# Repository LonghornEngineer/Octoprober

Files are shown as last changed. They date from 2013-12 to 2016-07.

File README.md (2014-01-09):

Octoprober
==========

Temperature logger designed to read 8 different K-type thermocouples. Can log data onto a SD card or to a host computer. Uses a character display for settings and viewing data.

Board Files are for Cadsoft Eagle V6.0+

Created by:
Parker Dillmann
The Longhorn Engineer

http://longhornengineer.com/

Disclaimer and licensing information can be found below.
http://longhornengineer.com/diy/disclaimer/

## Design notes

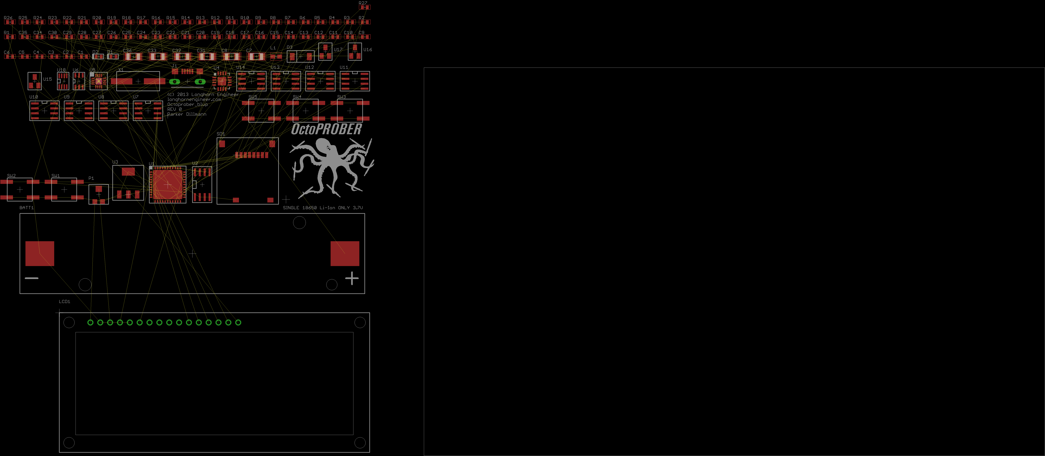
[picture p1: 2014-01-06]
Hardware/Start.png

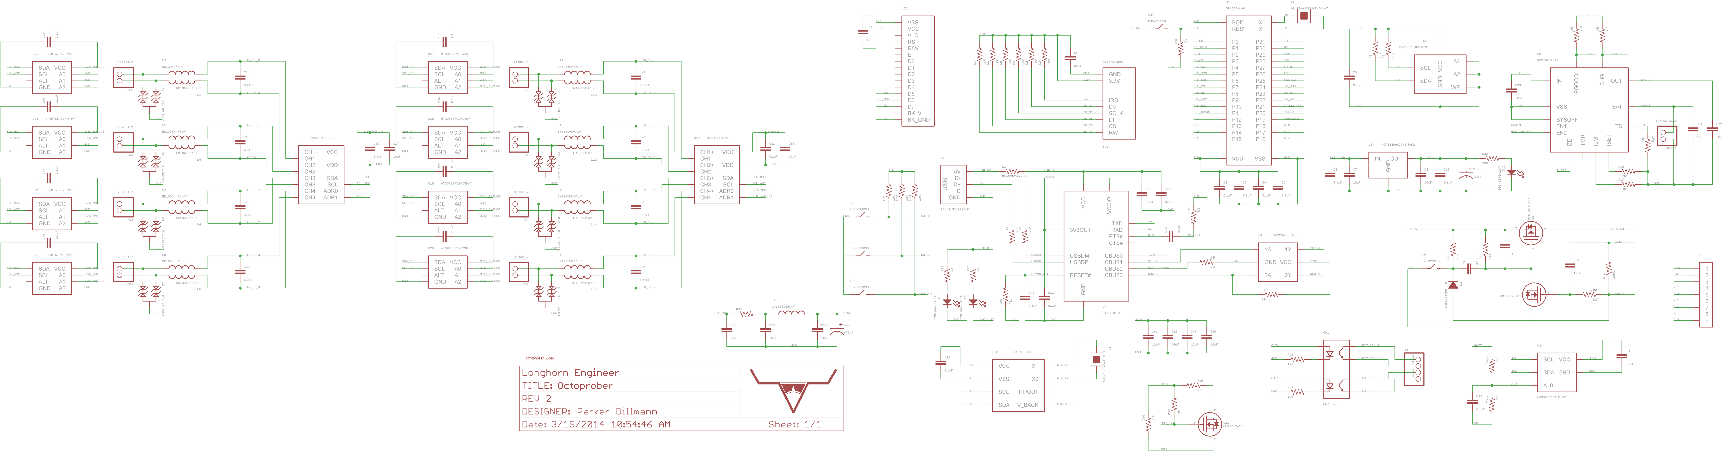
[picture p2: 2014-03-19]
Hardware/Schematic.png

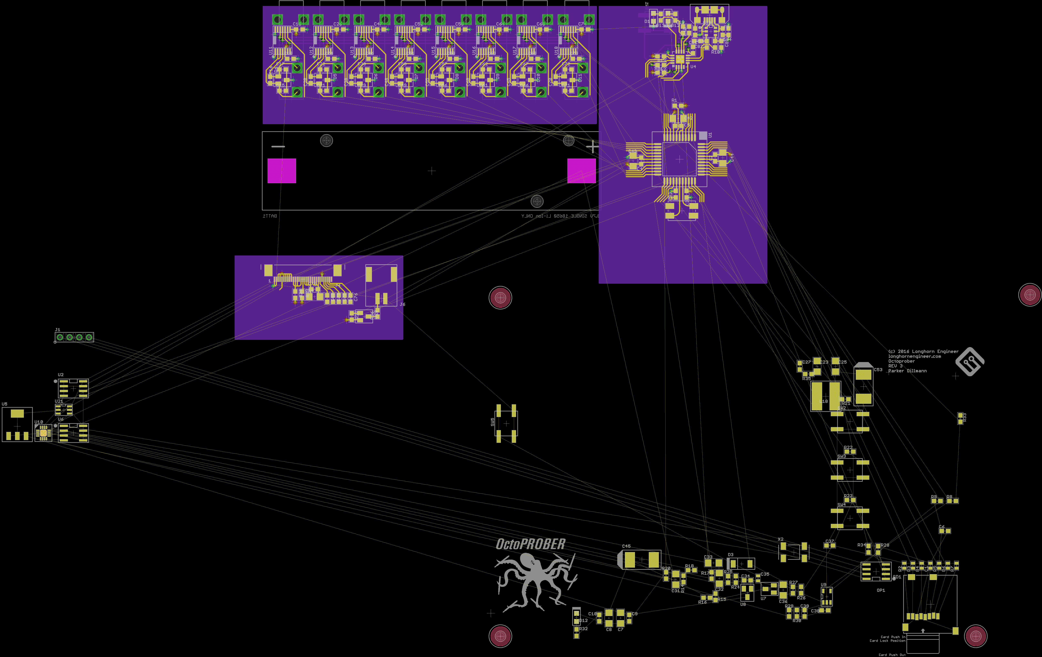
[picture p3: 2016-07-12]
Hardware/Layout.png

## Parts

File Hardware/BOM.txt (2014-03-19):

"Part";"Value";"Device";"Package";"Description";"DNAME";"REVNUM";
"BATT1";"MIKROE-1120";"PH_1X02HEADER_PTH";"HEADER_01X02_PTH";"2 pin connectors";"";"";
"C1";"0.1uF";"CAPACITOR_NON_POLAR0402";"0402";"Capacitor Non Polarized";"";"";
"C2";"0.1uF";"CAPACITOR_NON_POLAR0402";"0402";"Capacitor Non Polarized";"";"";
"C3";"0.1uF";"CAPACITOR_NON_POLAR0402";"0402";"Capacitor Non Polarized";"";"";
"C4";"0.1uF";"CAPACITOR_NON_POLAR0402";"0402";"Capacitor Non Polarized";"";"";
"C5";"0.1uF";"CAPACITOR_NON_POLAR0402";"0402";"Capacitor Non Polarized";"";"";
"C6";"0.1uF";"CAPACITOR_NON_POLAR0402";"0402";"Capacitor Non Polarized";"";"";
"C7";"10uF";"CAPACITOR_NON_POLAR1206";"1206";"Capacitor Non Polarized";"";"";
"C8";"10uF";"CAPACITOR_NON_POLAR1206";"1206";"Capacitor Non Polarized";"";"";
"C9";"0.1uF";"CAPACITOR_NON_POLAR0402";"0402";"Capacitor Non Polarized";"";"";
"C10";"0.1uF";"CAPACITOR_NON_POLAR0402";"0402";"Capacitor Non Polarized";"";"";
"C11";"0.1uF";"CAPACITOR_NON_POLAR0402";"0402";"Capacitor Non Polarized";"";"";
"C12";"0.1uF";"CAPACITOR_NON_POLAR0402";"0402";"Capacitor Non Polarized";"";"";
"C13";"0.1uF";"CAPACITOR_NON_POLAR0402";"0402";"Capacitor Non Polarized";"";"";
"C14";"0.1uF";"CAPACITOR_NON_POLAR0402";"0402";"Capacitor Non Polarized";"";"";
"C15";"0.1uF";"CAPACITOR_NON_POLAR0402";"0402";"Capacitor Non Polarized";"";"";
"C16";"0.01uF";"CAPACITOR_NON_POLAR0402";"0402";"Capacitor Non Polarized";"";"";
"C17";"10uF";"CAPACITOR_NON_POLAR0402";"0402";"Capacitor Non Polarized";"";"";
"C18";"0.01uF";"CAPACITOR_NON_POLAR0402";"0402";"Capacitor Non Polarized";"";"";
"C19";"10uF";"CAPACITOR_NON_POLAR0402";"0402";"Capacitor Non Polarized";"";"";
"C20";"0.01uF";"CAPACITOR_NON_POLAR0402";"0402";"Capacitor Non Polarized";"";"";
"C21";"0.1uF";"CAPACITOR_NON_POLAR0402";"0402";"Capacitor Non Polarized";"";"";
"C22";"0.01uF";"CAPACITOR_NON_POLAR0402";"0402";"Capacitor Non Polarized";"";"";
"C23";"10uF";"CAPACITOR_NON_POLAR0402";"0402";"Capacitor Non Polarized";"";"";
"C24";"0.01uF";"CAPACITOR_NON_POLAR0402";"0402";"Capacitor Non Polarized";"";"";
"C25";"10uF";"CAPACITOR_NON_POLAR0402";"0402";"Capacitor Non Polarized";"";"";
"C26";"0.01uF";"CAPACITOR_NON_POLAR0402";"0402";"Capacitor Non Polarized";"";"";
"C27";"1uF";"CAPACITOR_NON_POLAR0402";"0402";"Capacitor Non Polarized";"";"";
"C28";"0.01uF";"CAPACITOR_NON_POLAR0402";"0402";"Capacitor Non Polarized";"";"";
"C29";"0.1uF";"CAPACITOR_NON_POLAR0402";"0402";"Capacitor Non Polarized";"";"";
"C30";"0.01uF";"CAPACITOR_NON_POLAR0402";"0402";"Capacitor Non Polarized";"";"";
"C31";"10uF";"CAPACITOR_NON_POLAR1206";"1206";"Capacitor Non Polarized";"";"";
"C32";"10uF";"CAPACITOR_NON_POLAR1206";"1206";"Capacitor Non Polarized";"";"";
"C33";"10uF";"CAPACITOR_NON_POLAR1206";"1206";"Capacitor Non Polarized";"";"";
"C34";"0.1uF";"CAPACITOR_NON_POLAR0402";"0402";"Capacitor Non Polarized";"";"";
"C35";"0.1uF";"CAPACITOR_NON_POLAR0402";"0402";"Capacitor Non Polarized";"";"";
"C36";"10uF";"CAPACITOR_NON_POLAR1206";"1206";"Capacitor Non Polarized";"";"";
"C37";"0.1uF";"CAPACITOR_NON_POLAR0402";"0402";"Capacitor Non Polarized";"";"";
"C38";"0.1uF";"CAPACITOR_NON_POLAR0402";"0402";"Capacitor Non Polarized";"";"";
"C39";"0.1uF";"CAPACITOR_NON_POLAR0402";"0402";"Capacitor Non Polarized";"";"";
"C40";"0.1uF";"CAPACITOR_NON_POLAR0402";"0402";"Capacitor Non Polarized";"";"";
"C41";"10uF";"CAPACITOR_NON_POLAR0402";"0402";"Capacitor Non Polarized";"";"";
"C42";"10uF";"CAPACITOR_NON_POLAR0402";"0402";"Capacitor Non Polarized";"";"";
"C43";"10uF";"CAPACITOR_NON_POLAR0402";"0402";"Capacitor Non Polarized";"";"";
"C44";"10uF";"CAPACITOR_NON_POLAR0402";"0402";"Capacitor Non Polarized";"";"";
"C45";"470uF";"CAPACITOR_POLARIZEDCASE_D";"CASE_D";"Polarized capacitors";"";"";
"C46";"0.1uF";"CAPACITOR_NON_POLAR0402";"0402";"Capacitor Non Polarized";"";"";
"C47";"0.1uF";"CAPACITOR_NON_POLAR0402";"0402";"Capacitor Non Polarized";"";"";
"C48";"0.1uF";"CAPACITOR_NON_POLAR0402";"0402";"Capacitor Non Polarized";"";"";
"C49";"0.1uF";"CAPACITOR_NON_POLAR0402";"0402";"Capacitor Non Polarized";"";"";
"C50";"0.1uF";"CAPACITOR_NON_POLAR0402";"0402";"Capacitor Non Polarized";"";"";
"C51";"0.1uF";"CAPACITOR_NON_POLAR0402";"0402";"Capacitor Non Polarized";"";"";
"C52";"0.1uF";"CAPACITOR_NON_POLAR0402";"0402";"Capacitor Non Polarized";"";"";
"C53";"470uF";"CAPACITOR_POLARIZEDCASE_D";"CASE_D";"Polarized capacitors";"";"";
"C54";"1uF";"CAPACITOR_NON_POLAR0402";"0402";"Capacitor Non Polarized";"";"";
"D1";"598-8070-107F";"LED_SINGLE0402";"LED_0402";"";"";"";
"D2";"598-8070-107F";"LED_SINGLE0402";"LED_0402";"";"";"";
"D3";"PMEG6030EP,115";"DIODESOD-128";"SOD-128";"Diode - Single";"";"";
"D4";"NUP2105LT1G";"TVS_DIODE_DUALSOT-23";"SOT-23";"";"";"";
"D5";"NUP2105LT1G";"TVS_DIODE_DUALSOT-23";"SOT-23";"";"";"";
"D6";"NUP2105LT1G";"TVS_DIODE_DUALSOT-23";"SOT-23";"";"";"";
"D7";"NUP2105LT1G";"TVS_DIODE_DUALSOT-23";"SOT-23";"";"";"";
"D8";"NUP2105LT1G";"TVS_DIODE_DUALSOT-23";"SOT-23";"";"";"";
"D9";"NUP2105LT1G";"TVS_DIODE_DUALSOT-23";"SOT-23";"";"";"";
"D10";"NUP2105LT1G";"TVS_DIODE_DUALSOT-23";"SOT-23";"";"";"";
"D11";"NUP2105LT1G";"TVS_DIODE_DUALSOT-23";"SOT-23";"";"";"";
"D12";"598-8070-107F";"LED_SINGLE0402";"LED_0402";"";"";"";
"FU";"";"PH_1X09PTH";"HEADER_01X09_PTH";"";"";"";
"J1";"10118193-0001LF";"USB10118193-0001LF";"10118193-0001LF";"";"";"";
"J2";"";"PH_1X04HEADER_PTH";"HEADER_01X04_PTH";"4 Pin Connectors";"";"";
"L1";"MI0603K300R-10";"RESISTOR0603";"0603";"Resistors";"";"";
"L2";"BK1005HM471-T";"INDUCTOR0402";"0402";"Inductors";"";"";
"L3";"BK1005HM471-T";"INDUCTOR0402";"0402";"Inductors";"";"";
"L4";"BK1005HM471-T";"INDUCTOR0402";"0402";"Inductors";"";"";
"L5";"BK1005HM471-T";"INDUCTOR0402";"0402";"Inductors";"";"";
"L6";"BK1005HM471-T";"INDUCTOR0402";"0402";"Inductors";"";"";
"L7";"BK1005HM471-T";"INDUCTOR0402";"0402";"Inductors";"";"";
"L8";"BK1005HM471-T";"INDUCTOR0402";"0402";"Inductors";"";"";
"L9";"BK1005HM471-T";"INDUCTOR0402";"0402";"Inductors";"";"";
"L10";"BK1005HM471-T";"INDUCTOR0402";"0402";"Inductors";"";"";
"L11";"BK1005HM471-T";"INDUCTOR0402";"0402";"Inductors";"";"";
"L12";"BK1005HM471-T";"INDUCTOR0402";"0402";"Inductors";"";"";
"L13";"BK1005HM471-T";"INDUCTOR0402";"0402";"Inductors";"";"";
"L14";"BK1005HM471-T";"INDUCTOR0402";"0402";"Inductors";"";"";
"L15";"BK1005HM471-T";"INDUCTOR0402";"0402";"Inductors";"";"";
"L16";"BK1005HM471-T";"INDUCTOR0402";"0402";"Inductors";"";"";
"L17";"BK1005HM471-T";"INDUCTOR0402";"0402";"Inductors";"";"";
"L18";"LK1608100K-T";"INDUCTOR0603";"0603";"Inductors";"";"";
"LCD1";"";"HD44780_LCD1602_COUNTERSINK";"CHAR_DISPLAY_1602_COUNTERSINK";"";"";"";
"OP1";"ACPL-227";"ACPL-227SOIC-8";"SOIC-8";"";"";"";
"R1";"10K";"RESISTOR0402";"0402";"Resistors";"";"";
"R2";"10K";"RESISTOR0402";"0402";"Resistors";"";"";
"R3";"10K";"RESISTOR0402";"0402";"Resistors";"";"";
"R4";"10K";"RESISTOR0402";"0402";"Resistors";"";"";
"R5";"10K";"RESISTOR0402";"0402";"Resistors";"";"";
"R6";"10K";"RESISTOR0402";"0402";"Resistors";"";"";
"R7";"10K";"RESISTOR0402";"0402";"Resistors";"";"";
"R8";"10K";"RESISTOR0402";"0402";"Resistors";"";"";
"R9";"10K";"RESISTOR0402";"0402";"Resistors";"";"";
"R10";"22";"RESISTOR0402";"0402";"Resistors";"";"";
"R11";"22";"RESISTOR0402";"0402";"Resistors";"";"";
"R12";"330";"RESISTOR0402";"0402";"Resistors";"";"";
"R13";"330";"RESISTOR0402";"0402";"Resistors";"";"";
"R14";"10K";"RESISTOR0402";"0402";"Resistors";"";"";
"R15";"10K";"RESISTOR0402";"0402";"Resistors";"";"";
"R16";"10K";"RESISTOR0402";"0402";"Resistors";"";"";
"R17";"1.18K";"RESISTOR0402";"0402";"Resistors";"";"";
"R18";"1.13K";"RESISTOR0402";"0402";"Resistors";"";"";
"R19";"10K";"RESISTOR0402";"0402";"Resistors";"";"";
"R20";"10K";"RESISTOR0402";"0402";"Resistors";"";"";
"R21";"10K";"RESISTOR0402";"0402";"Resistors";"";"";
"R22";"10K";"RESISTOR0402";"0402";"Resistors";"";"";
"R23";"10K";"RESISTOR0402";"0402";"Resistors";"";"";
"R24";"100K";"RESISTOR0402";"0402";"Resistors";"";"";
"R25";"10K";"RESISTOR0402";"0402";"Resistors";"";"";
"R26";"100K";"RESISTOR0402";"0402";"Resistors";"";"";
"R27";"300K";"RESISTOR0402";"0402";"Resistors";"";"";
"R28";"120";"RESISTOR0402";"0402";"Resistors";"";"";
"R29";"100K";"RESISTOR0402";"0402";"Resistors";"";"";
"R30";"254K";"RESISTOR0402";"0402";"Resistors";"";"";
"R31";"10K";"RESISTOR0402";"0402";"Resistors";"";"";
"R32";"330";"RESISTOR0402";"0402";"Resistors";"";"";
"R33";"10K";"RESISTOR0402";"0402";"Resistors";"";"";
"R34";"120";"RESISTOR0402";"0402";"Resistors";"";"";
"R35";"1";"RESISTOR0402";"0402";"Resistors";"";"";
"R36";"10K";"RESISTOR0402";"0402";"Resistors";"";"";
"R37";"560";"RESISTOR0402";"0402";"Resistors";"";"";
"R38";"560";"RESISTOR0402";"0402";"Resistors";"";"";
"SD1";"502570-0893";"SD_CARD502570-0893";"502570-0893";"";"";"";
"SW1";"EVQ-Q2203W";"SPSTEVQ-Q2203W";"EVQ-Q2203W";"SPST Switches";"";"";
"SW2";"EVQ-Q2203W";"SPSTEVQ-Q2203W";"EVQ-Q2203W";"SPST Switches";"";"";
"SW3";"EVQ-Q2203W";"SPSTEVQ-Q2203W";"EVQ-Q2203W";"SPST Switches";"";"";
"SW4";"EVQ-Q2203W";"SPSTEVQ-Q2203W";"EVQ-Q2203W";"SPST Switches";"";"";
"SW5";"EVQ-Q2203W";"SPSTEVQ-Q2203W";"EVQ-Q2203W";"SPST Switches";"";"";
"TC1";"282834-2";"PH_1X02SCREW_TERM";"HEADER_01X02_PTH_SCREWTERM";"2 pin connectors";"";"";
"TC2";"282834-2";"PH_1X02SCREW_TERM";"HEADER_01X02_PTH_SCREWTERM";"2 pin connectors";"";"";
"TC3";"282834-2";"PH_1X02SCREW_TERM";"HEADER_01X02_PTH_SCREWTERM";"2 pin connectors";"";"";
"TC4";"282834-2";"PH_1X02SCREW_TERM";"HEADER_01X02_PTH_SCREWTERM";"2 pin connectors";"";"";
"TC5";"282834-2";"PH_1X02SCREW_TERM";"HEADER_01X02_PTH_SCREWTERM";"2 pin connectors";"";"";
"TC6";"282834-2";"PH_1X02SCREW_TERM";"HEADER_01X02_PTH_SCREWTERM";"2 pin connectors";"";"";
"TC7";"282834-2";"PH_1X02SCREW_TERM";"HEADER_01X02_PTH_SCREWTERM";"2 pin connectors";"";"";
"TC8";"282834-2";"PH_1X02SCREW_TERM";"HEADER_01X02_PTH_SCREWTERM";"2 pin connectors";"";"";
"U$1";"LHE_FRAME";"LHE_FRAME";"LHE_FRAME";"";"Parker Dillmann";"REV 2";
"U$2";"OCTOPROBER_LOGONORMAL";"OCTOPROBER_LOGONORMAL";"OCTOPROBER_LOGO";"";"";"";
"U1";"P8X32A-M44";"P8X32A_PROPELLERQFN-44";"QFN-44";"";"";"";
"U2";"CAT24C512WI-GT3";"CAT24M01XI-T2SOIC-8_W";"SOIC-8_W";"";"";"";
"U3";"ADP3338AKCZ-3.3-RL";"FIXED_VOLTAGE_REGSOT-223_ALT";"SOT-223";"";"";"";
"U4";"FT230XQ-R";"FT230XQFN-16";"QFN-16";"Manufacturer Part #: FT230XS-R";"";"";
"U5";"BQ24075RGTT";"BQ2407XQFN-16";"QFN-16_BOT_PAD";"";"";"";
"U6";"74HC2G04GV,125";"74HCT2G04GV,125TTSOP-6";"TTSOP-6";"";"";"";
"U7";"PMV22EN,215";"MOSFET_N-CHANNEL_SINGLESOT-23";"SOT-23";"Mosfet - N-Channel - Single";"";"";
"U8";"PMV160UP,215";"MOSFET_P-CHANNEL_SINGLESOT-23";"SOT-23";"";"";"";
"U9";"MCP3021A5T-E/OT";"MCP3021SOT-23A";"SOT-23A";"";"";"";
"U10";"DS1340Z-33+";"DS1340SOIC-8";"SOIC-8";"";"";"";
"U11";"MCP3424-E/ST";"MCP3424TTSOP-14";"TTSOP-14";"";"";"";
"U12";"MCP3424-E/ST";"MCP3424TTSOP-14";"TTSOP-14";"";"";"";
"U13";"AT30TSE752-XM8-T";"AT30TSEXXXMSOP-8";"MSOP-8";"";"";"";
"U14";"AT30TSE752-XM8-T";"AT30TSEXXXMSOP-8";"MSOP-8";"";"";"";
"U15";"AT30TSE752-XM8-T";"AT30TSEXXXMSOP-8";"MSOP-8";"";"";"";
"U16";"AT30TSE752-XM8-T";"AT30TSEXXXMSOP-8";"MSOP-8";"";"";"";
"U17";"AT30TSE752-XM8-T";"AT30TSEXXXMSOP-8";"MSOP-8";"";"";"";
"U18";"AT30TSE752-XM8-T";"AT30TSEXXXMSOP-8";"MSOP-8";"";"";"";
"U19";"AT30TSE752-XM8-T";"AT30TSEXXXMSOP-8";"MSOP-8";"";"";"";
"U20";"AT30TSE752-XM8-T";"AT30TSEXXXMSOP-8";"MSOP-8";"";"";"";
"U21";"PMV22EN,215";"MOSFET_N-CHANNEL_SINGLESOT-23";"SOT-23";"Mosfet - N-Channel - Single";"";"";
"X1";"ABLS3-6.000MHZ-D4Y-T";"CRYSTALHC-49";"HC-49/US_SM";"";"";"";
"X2";"ABS25-32.768KHz-1-T";"CRYSTAL8MM_X_3.8MM";"8MM_X_3.8MM";"";"";"";

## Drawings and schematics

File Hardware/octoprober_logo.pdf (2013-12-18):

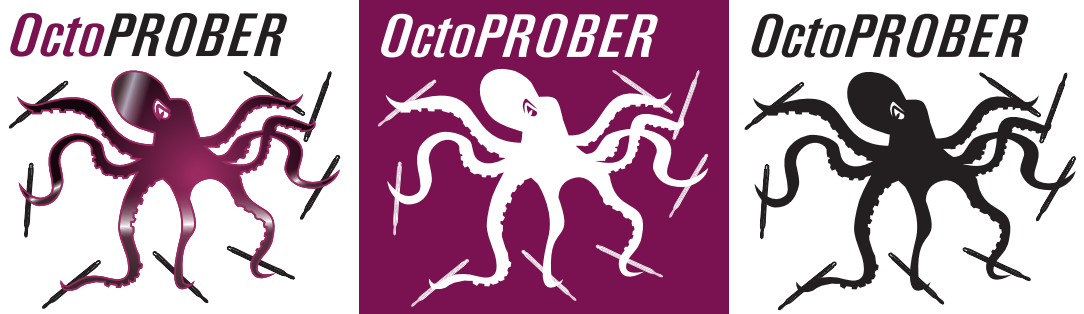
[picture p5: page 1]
OctoPROBER

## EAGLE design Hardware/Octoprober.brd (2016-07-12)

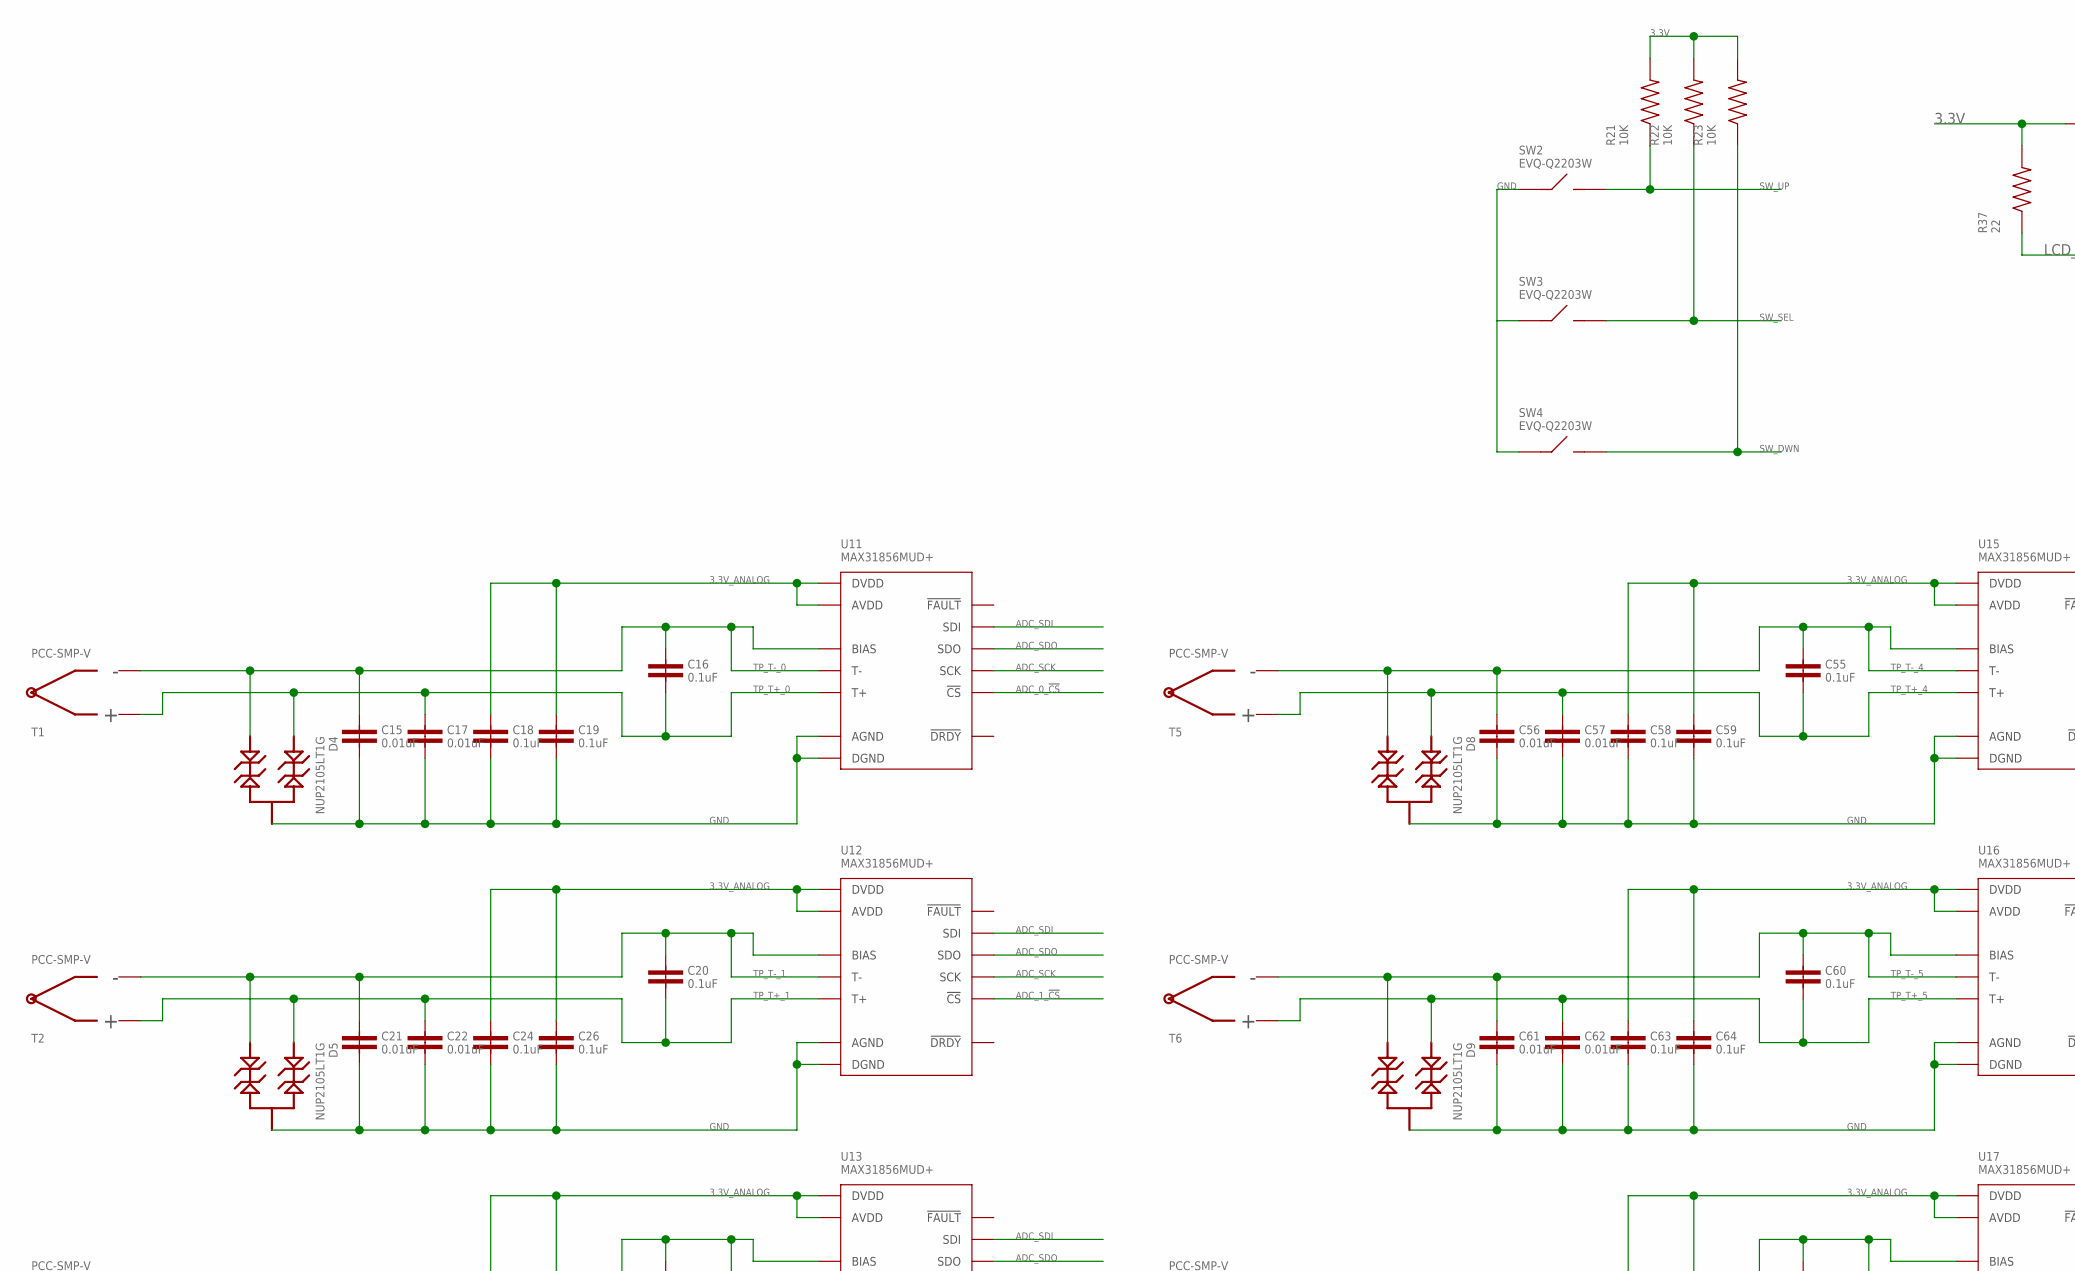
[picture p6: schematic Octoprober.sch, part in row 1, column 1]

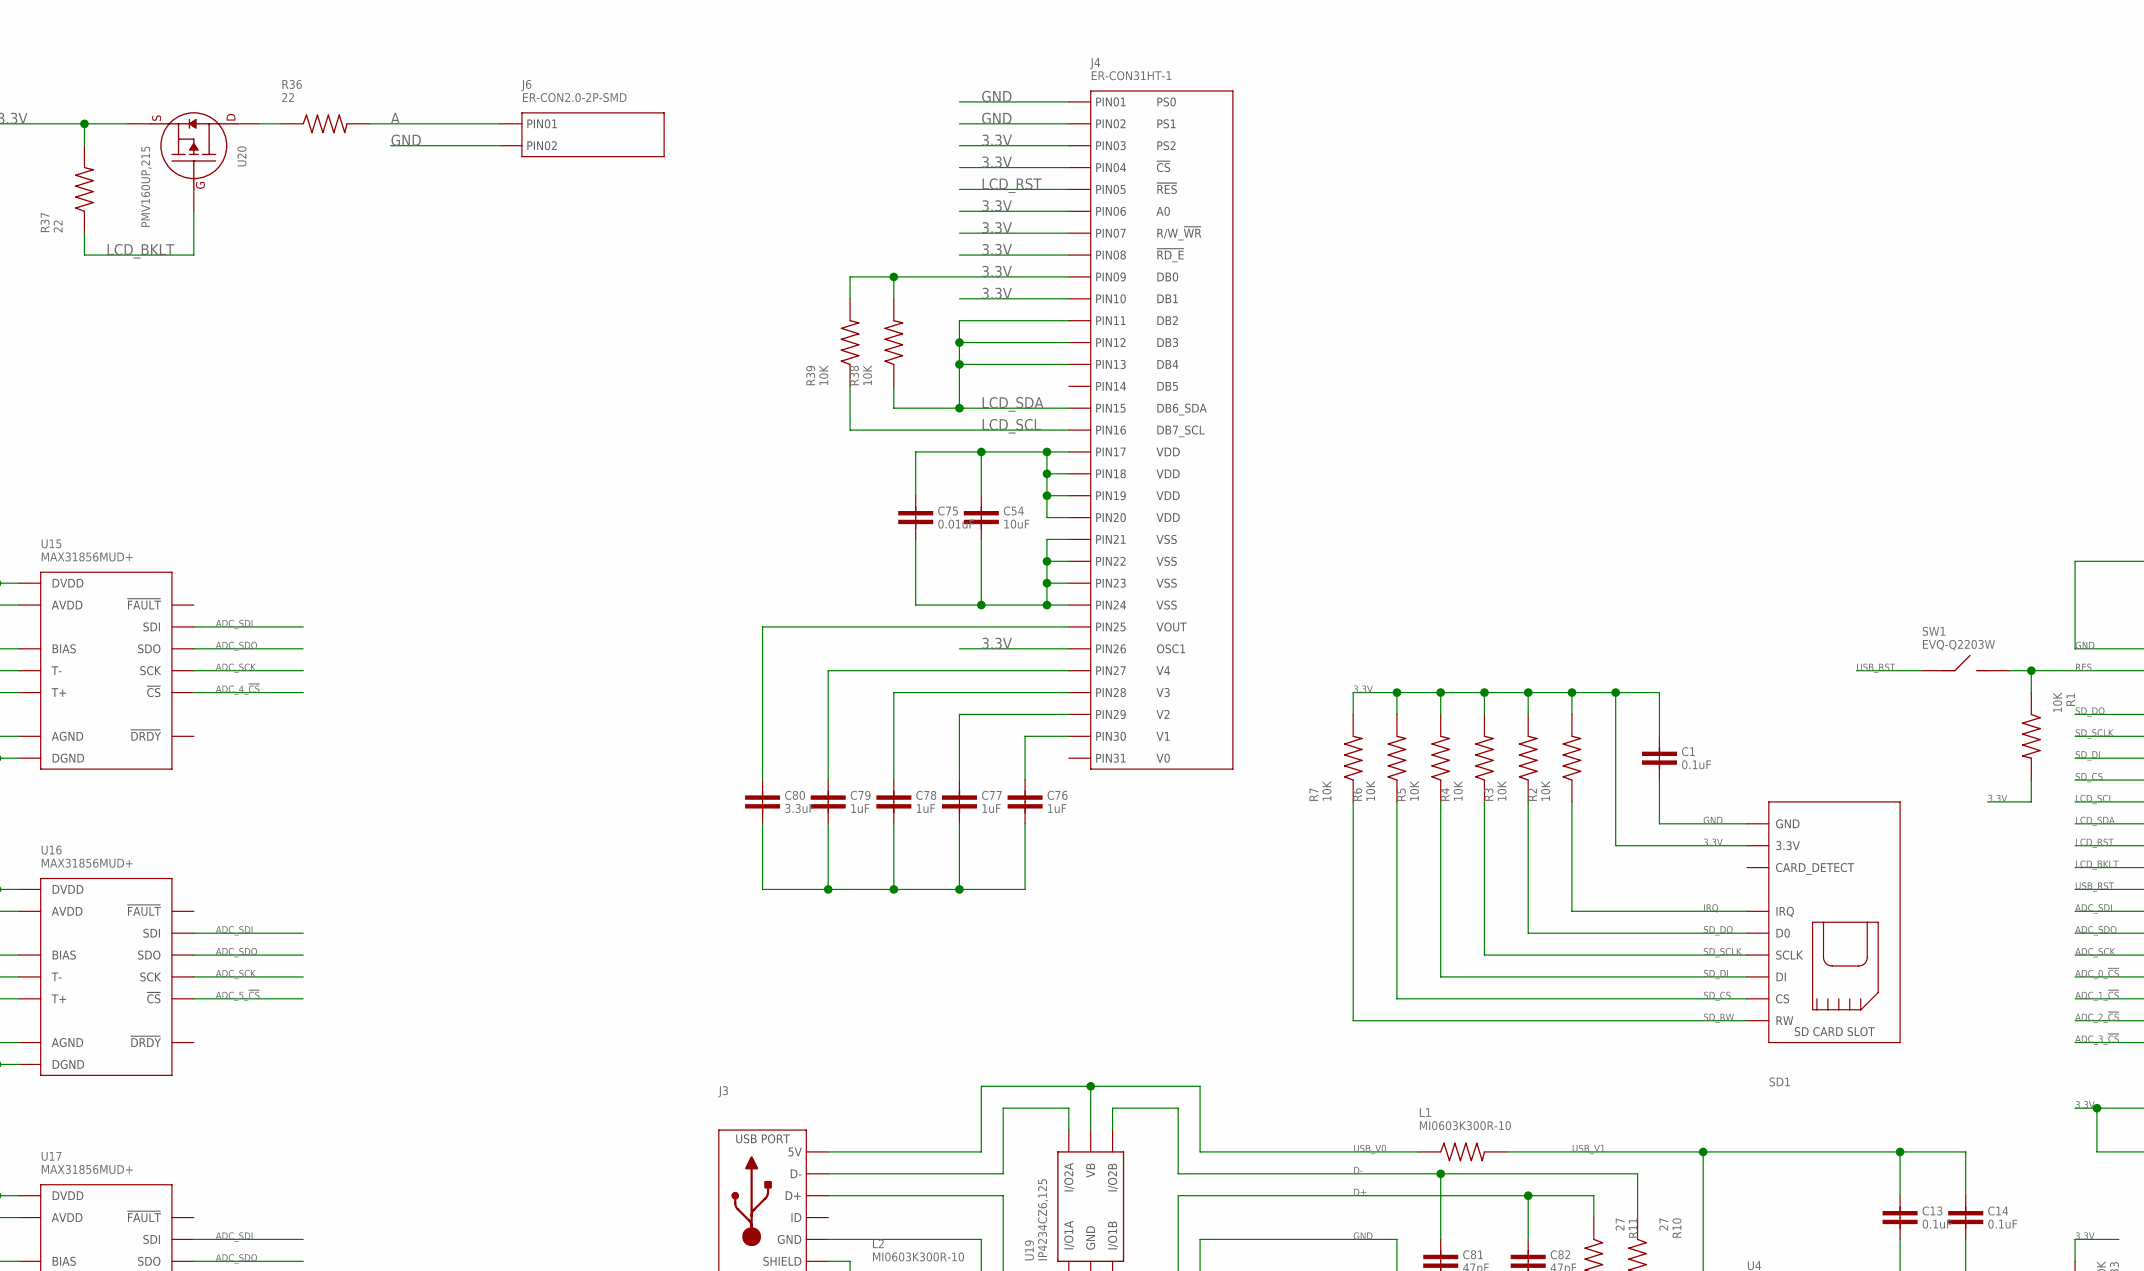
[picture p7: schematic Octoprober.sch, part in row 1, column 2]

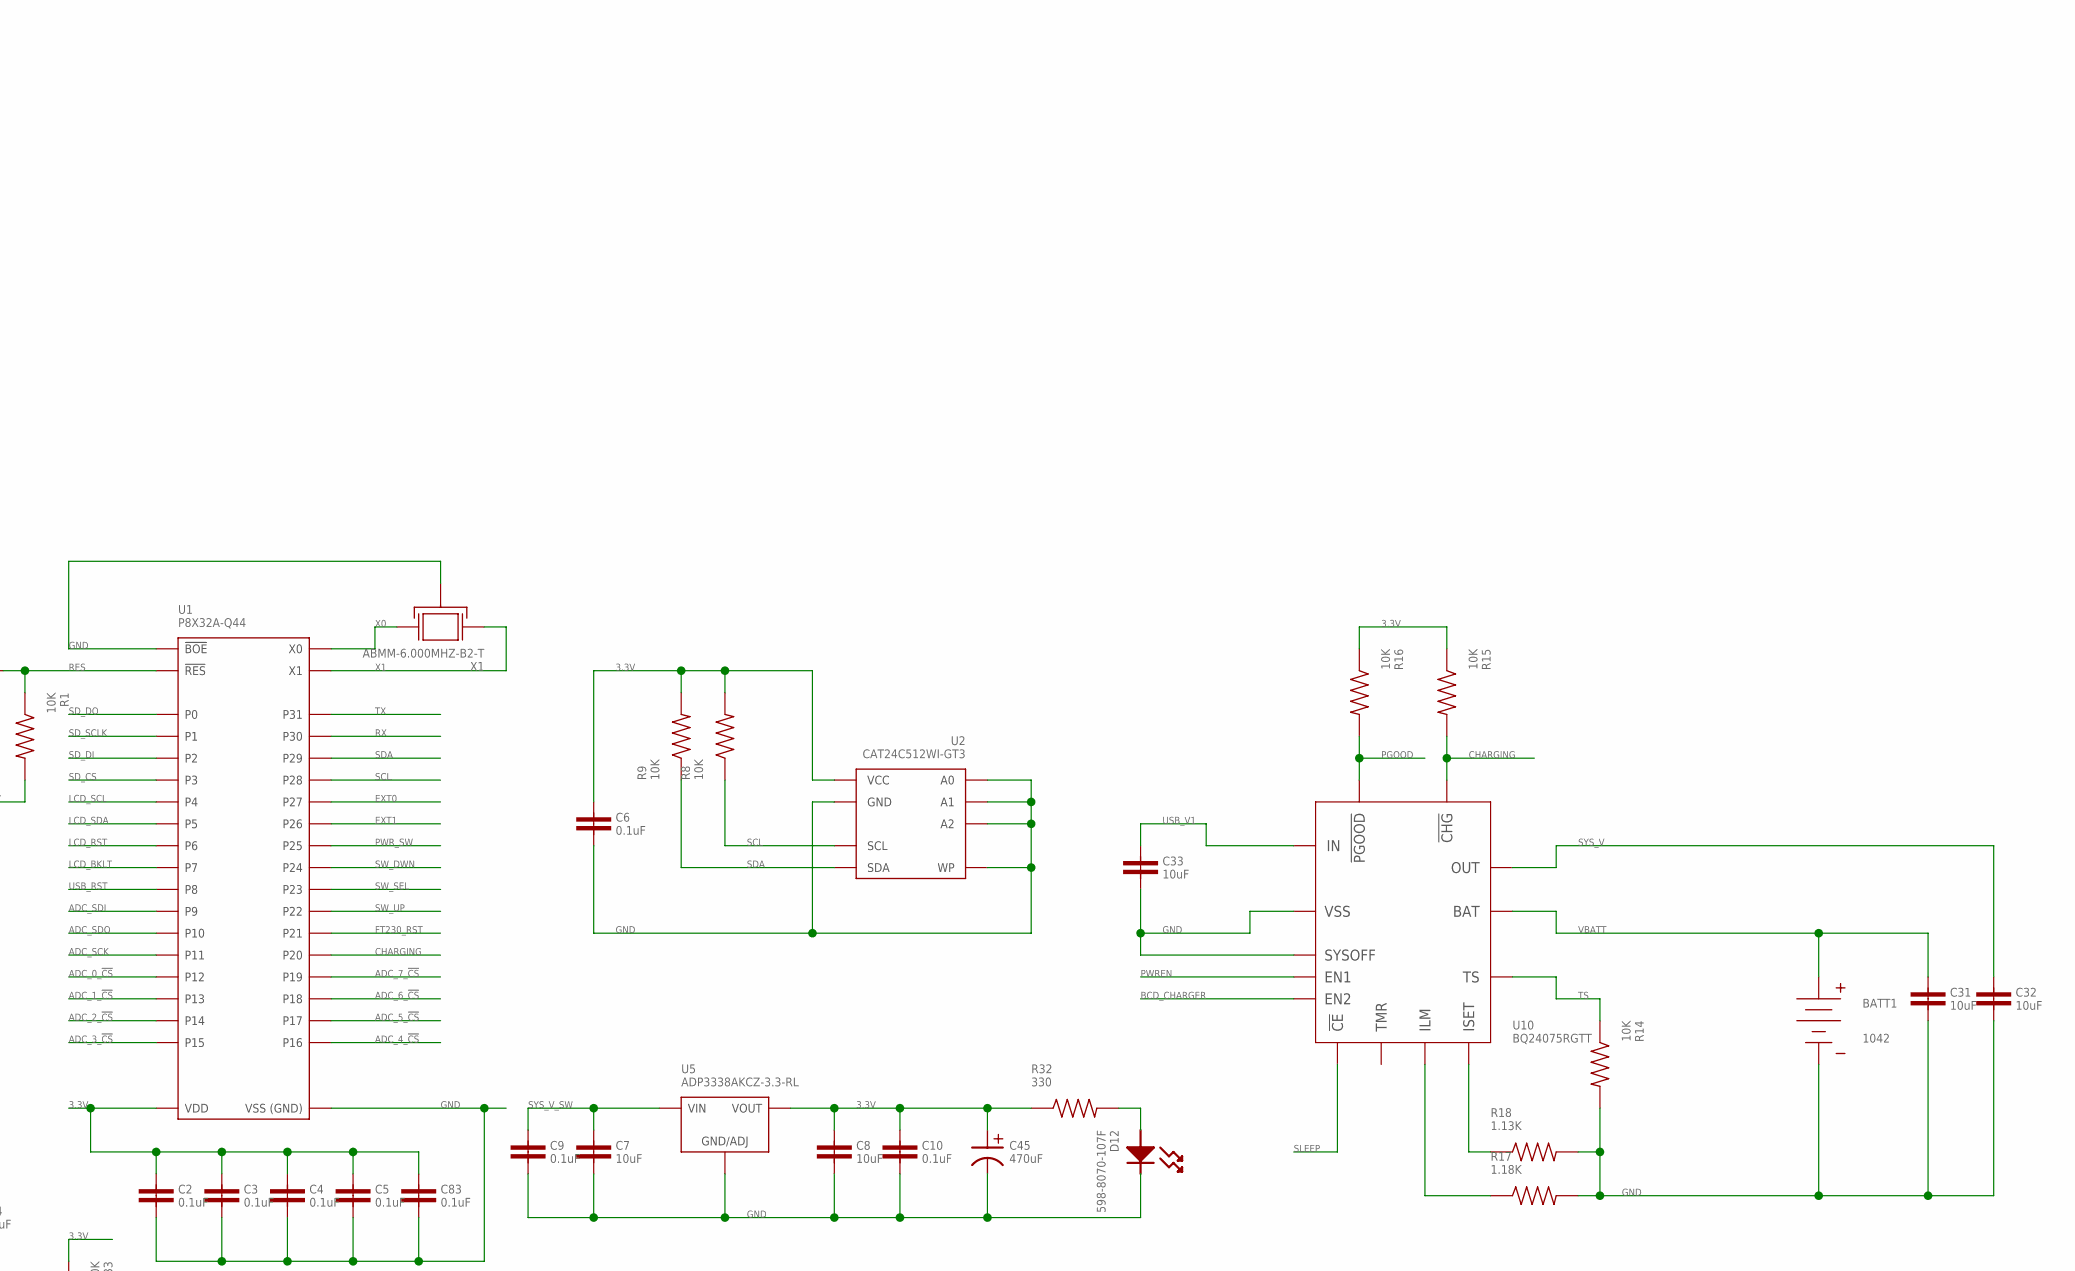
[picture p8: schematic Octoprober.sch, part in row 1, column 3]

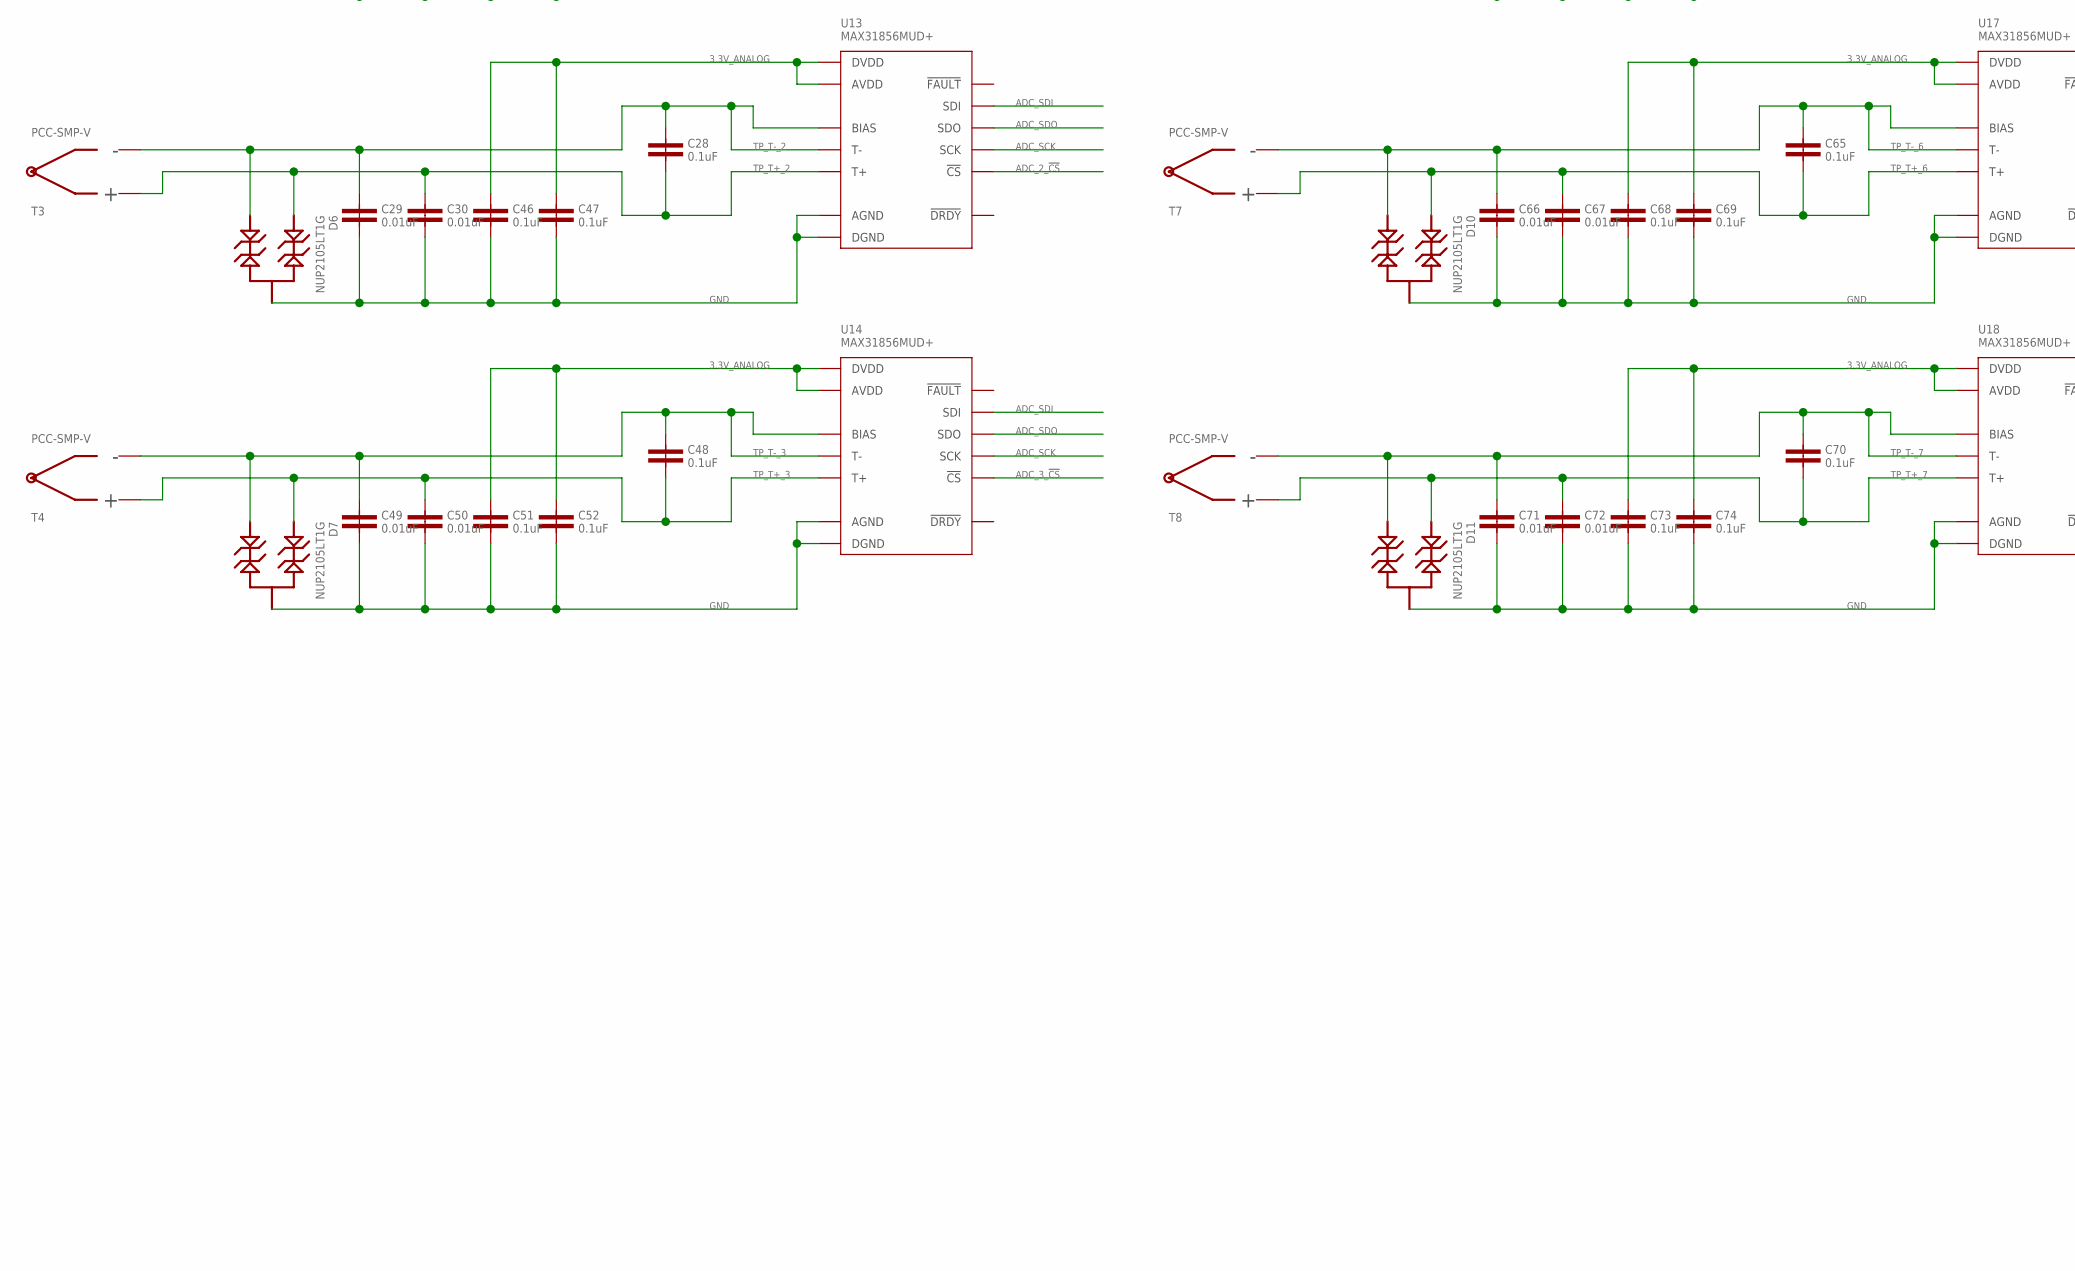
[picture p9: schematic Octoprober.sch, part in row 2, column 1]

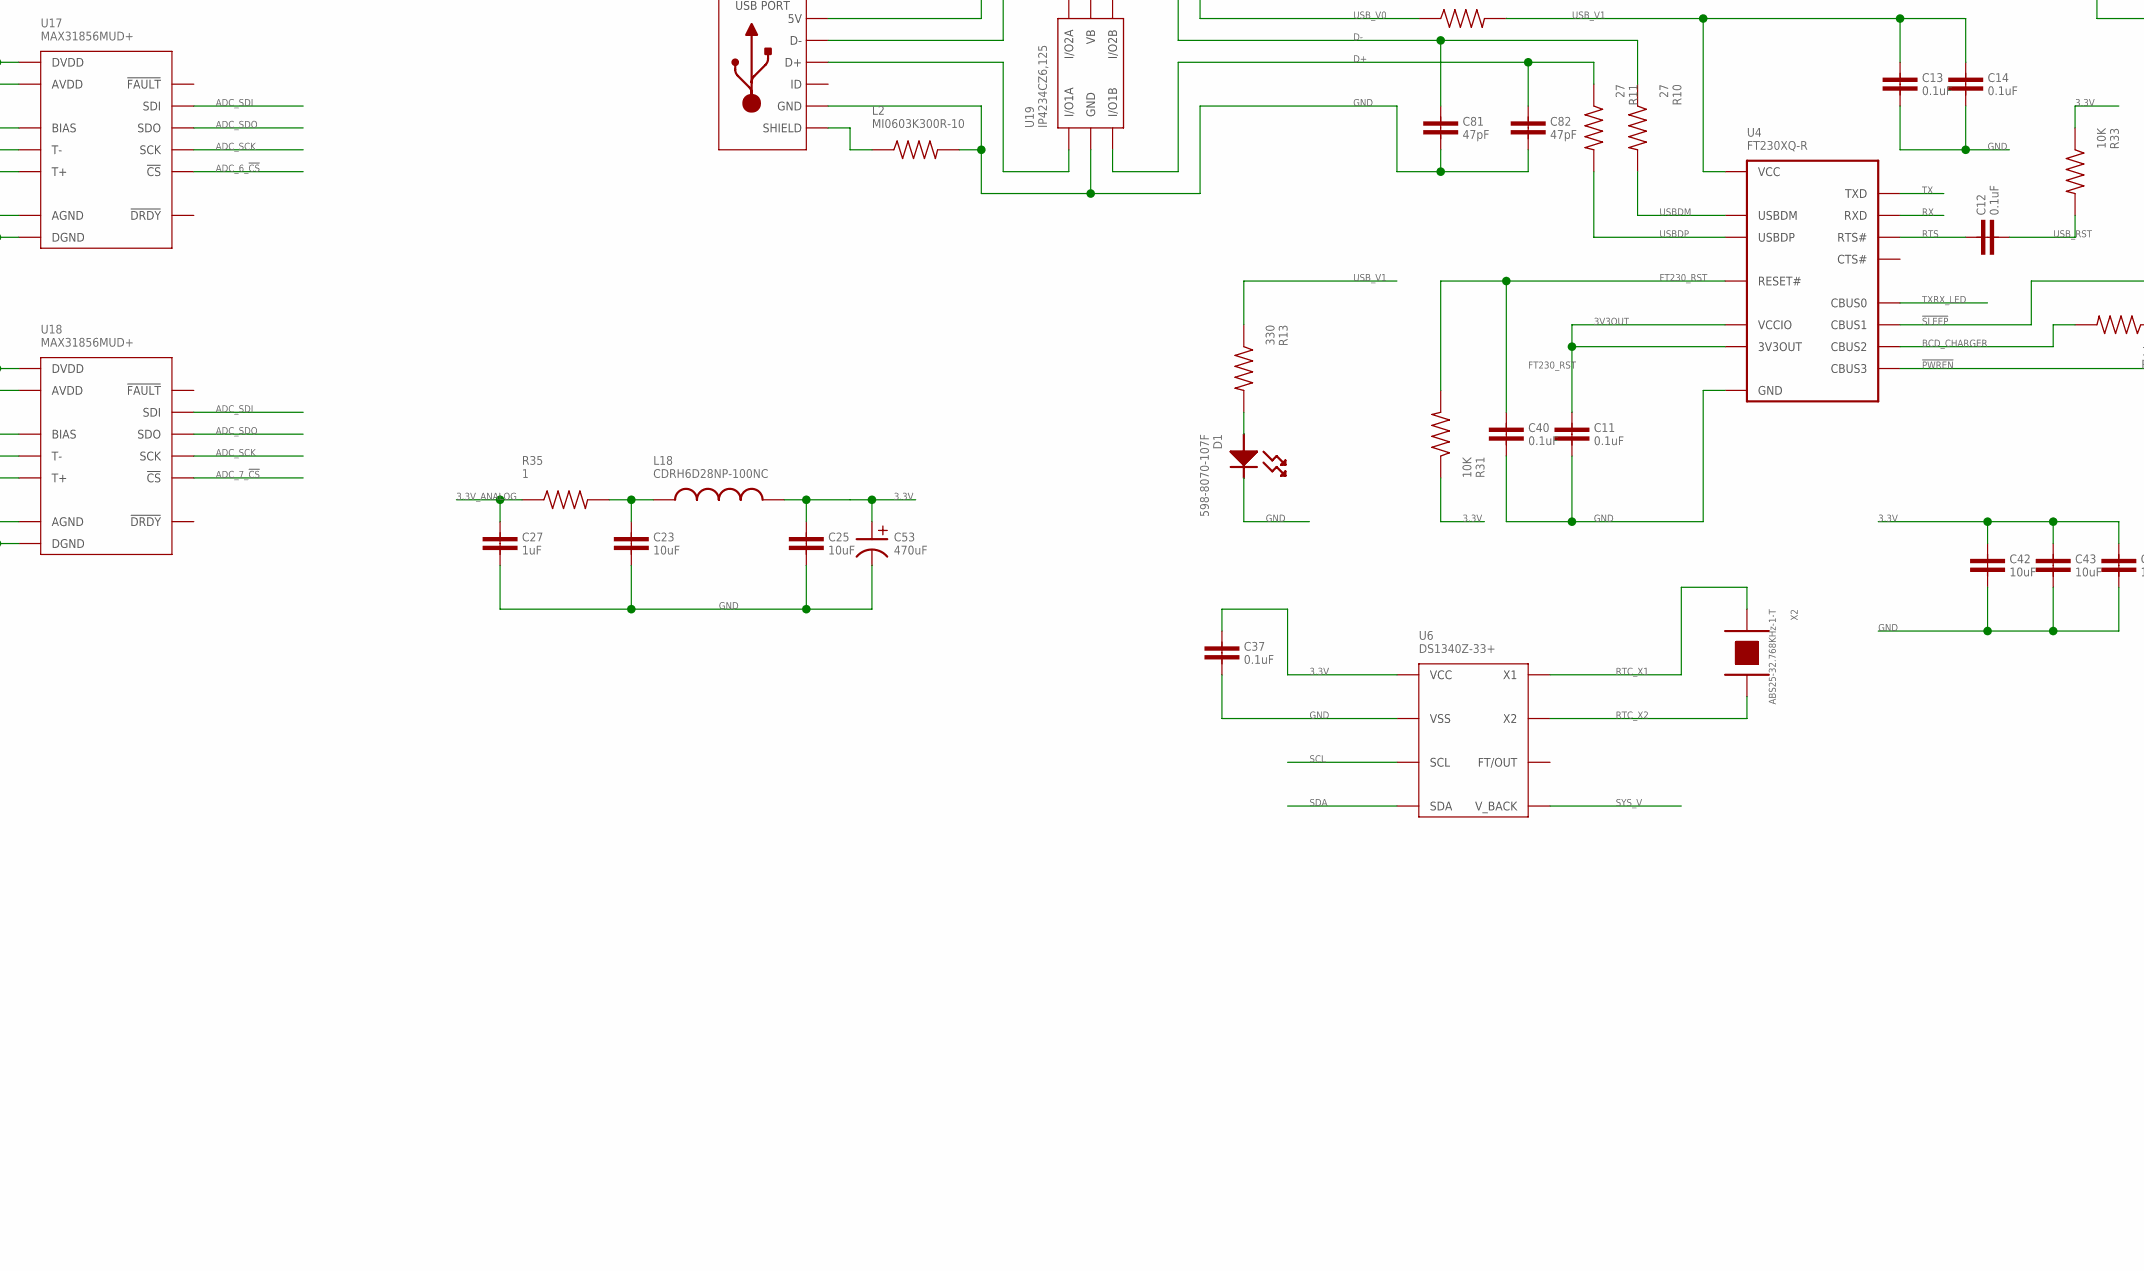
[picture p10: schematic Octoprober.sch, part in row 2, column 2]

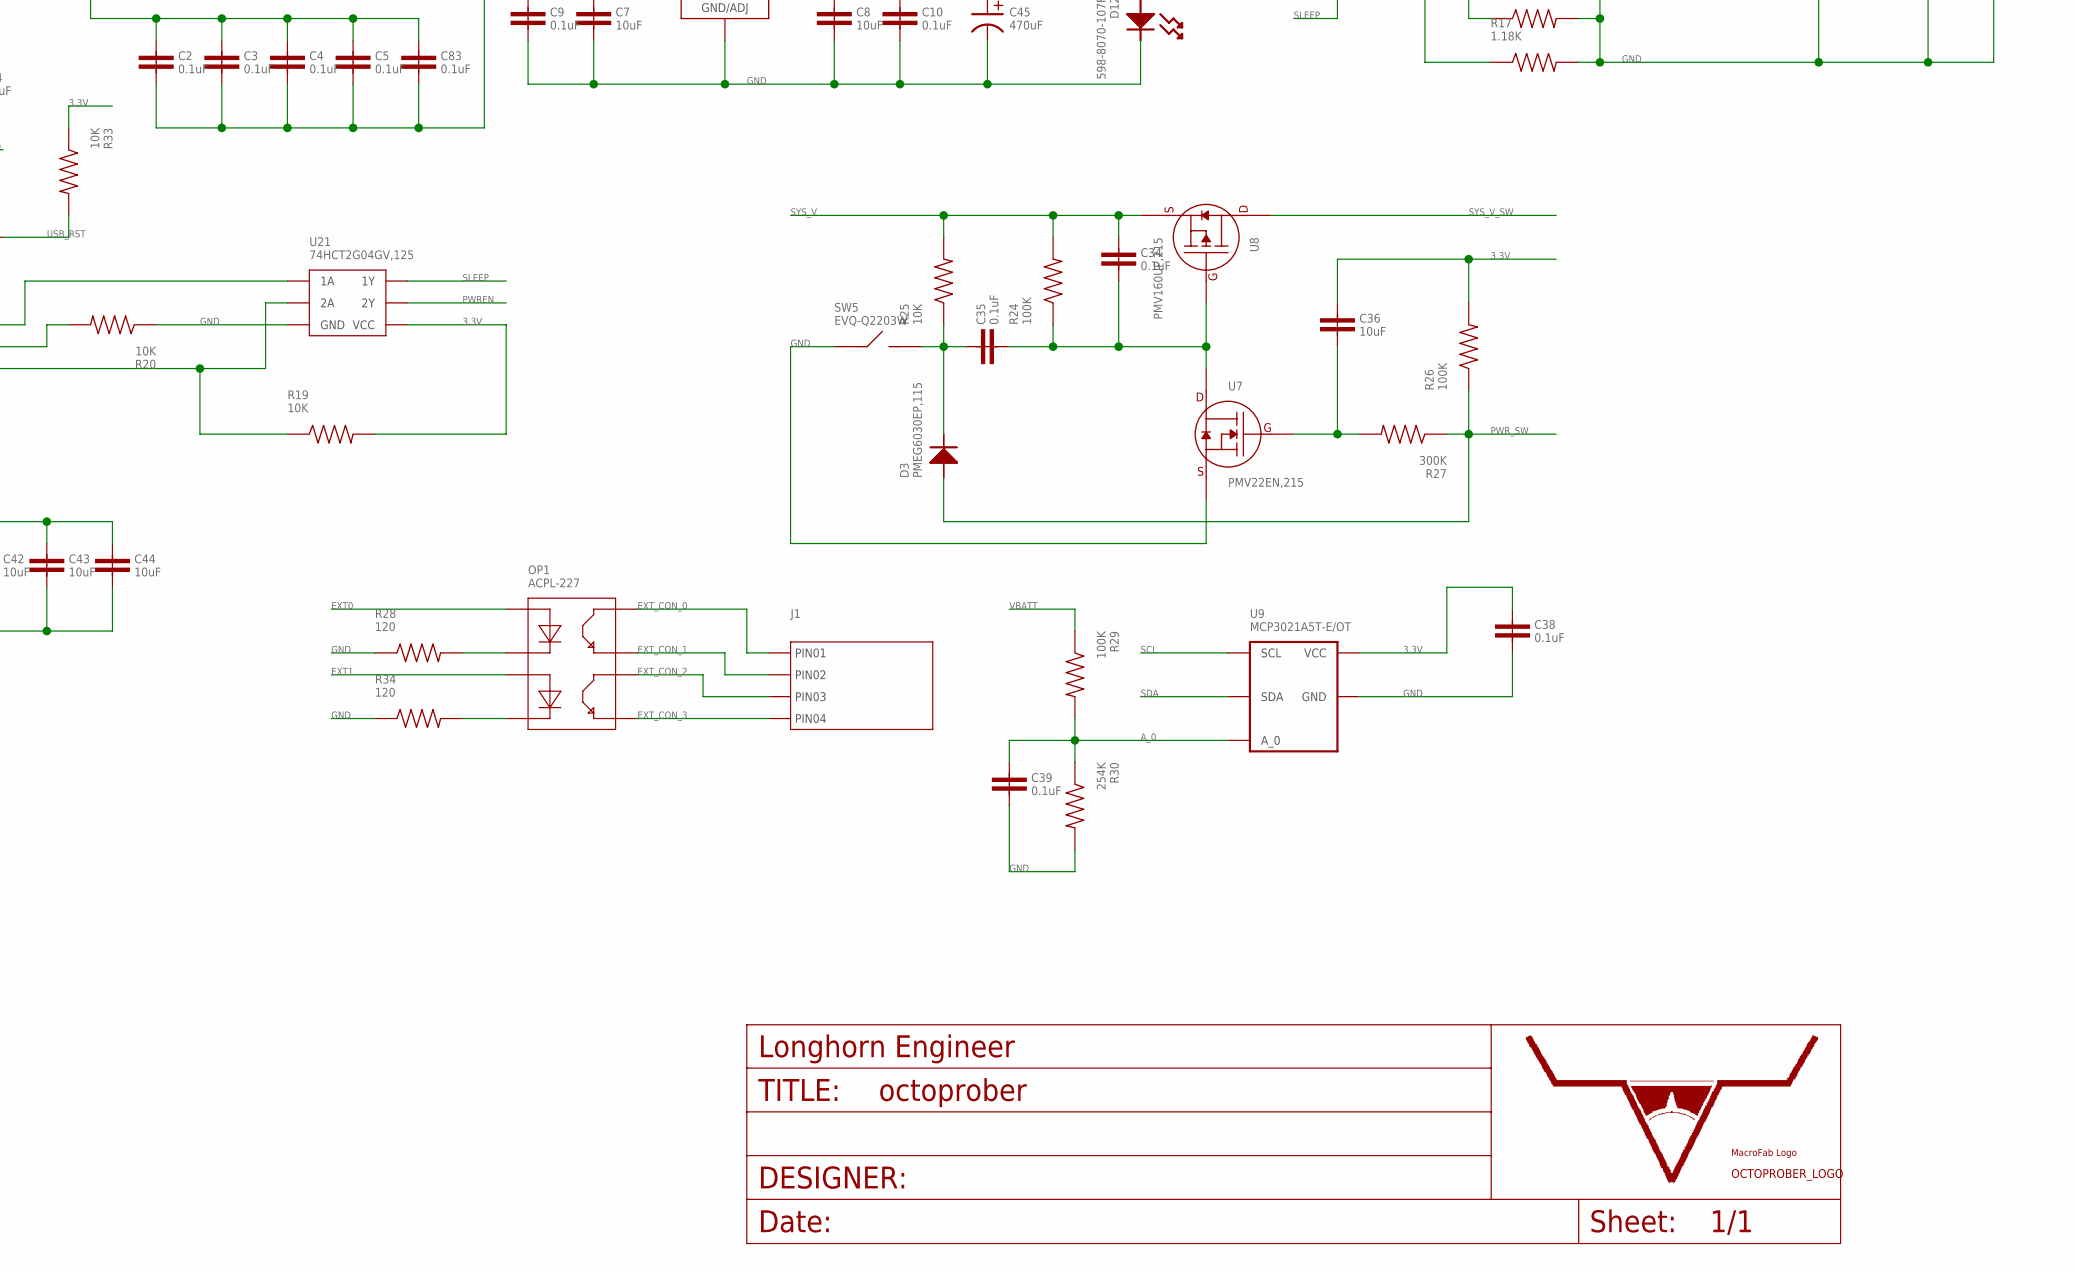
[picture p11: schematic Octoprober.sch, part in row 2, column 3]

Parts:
BATT1: 1042; KEYSTONE_1042
C1, C35: 0.1uF; 0402
C2, C3, C4, C5, C6, C9, C10, C11, C12, C13, C14, C16, C18, C19, C20, C24, C26, C28, C34, C37, C38, C39, C40, C46, C47, C48, C51, C52, C55, C58, C59, C60, C63, C64, C65, C68, C69, C70, C73, C74, C83: 0.1uF; 0603
C7, C8, C23, C25, C31, C32, C33, C36, C42, C43, C44, C54: 10uF; 1206
C15, C17, C21, C22, C29, C30, C49, C50, C56, C57, C61, C62, C66, C67, C71, C72, C75: 0.01uF; 0603
C27, C76, C77, C78, C79: 1uF; 0603
C45, C53: 470uF; CASE_D
C80: 3.3uF; 0603
C81, C82: 47pF; 0603
D1, D12: 598-8070-107F; LED_0805
D3: PMEG6030EP,115; SOD-128
D4, D5, D6, D7, D8, D9, D10, D11: NUP2105LT1G; SOT-23
J1: CON_01X04_2.54MM_PIN_HEADER; 2.54MM_01X04_PIN_HEADER
J3: USB_MICRO_RIGHT; MICROUSB-RIGHT
J4: ER-CON31HT-1
J6: ER-CON2.0-2P-SMD
L1, L2: MI0603K300R-10; 0603
L18: CDRH6D28NP-100NC; CDRH6D28
OP1: ACPL-227; ACPL-227_SO-8
R1, R8, R9, R14, R15, R16, R19, R20, R21, R22, R23, R25, R31, R33, R38, R39: 10K; 0603
R2, R3, R4, R5, R6, R7: 10K; 0402
R10, R11: 27; 0603
R13, R32: 330; 0603
R17: 1.18K; 0603
R18: 1.13K; 0603
R24, R26, R29: 100K; 0603
R27: 300K; 0603
R28, R34: 120; 0603
R30: 254K; 0603
R35: 1; 0603
R36, R37: 22; 0603
SD1: SD_CARD_SLOT_MICRO_RIGHT; MICROSDSLOT-RIGHT
SW1, SW2, SW3, SW4, SW5: EVQ-Q2203W
T1, T2, T3, T4, T5, T6, T7, T8: PCC-SMP-V
U1: P8X32A-Q44; LQFP44
U2: CAT24C512WI-GT3; SOIC-8
U4: FT230XQ-R; FT230X_QFN-16
U5: ADP3338AKCZ-3.3-RL; ADP3338_SOT-223-3
U6: DS1340Z-33+; DS1340Z_SOIC-8
U7: PMV22EN,215; SOT-23-3
U8, U20: PMV160UP,215; SOT-23-3
U9: MCP3021A5T-E/OT; MCP3021_SOT-23-5
U10: BQ24075RGTT; BQ2407X_VQFN-16
U11, U12, U13, U14, U15, U16, U17, U18: MAX31856MUD+; MAX31856_TTSOP-14
U19: IP4234CZ6,125; IP4234CZ6_SOT-457-6
U21: 74HCT2G04GV,125; 74HCT2G04_TTSOP-6
U$1: LHE_FRAME
U$2: OCTOPROBER_LOGONORMAL; OCTOPROBER_LOGO
U$7: MF_LOGOLOGO_MEDIUM; MF_LOGO_MEDIUM
X1: ABMM-6.000MHZ-B2-T; 7MMX5MM
X2: ABS25-32.768KHz-1-T; 8MM_X_3.8MM

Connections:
3.3V: C1.1, C2.1, C3.1, C4.1, C5.1, C6.1, C8.1, C10.1, C25.1, C36.1, C37.1, C38.1, C42.1, C43.1, C44.1, C45.P (POS), C53.P (POS), C83.1, J4.P$3 (PIN3), J4.P$4 (PIN4), J4.P$6 (PIN6), J4.P$7 (PIN7), J4.P$8 (PIN8), J4.P$9 (PIN9), J4.P$10 (PIN10), J4.P$26 (PIN26), L18.P$2, R1.2, R2.2, R3.2, R4.2, R5.2, R6.2, R7.2, R8.2, R9.2, R15.1, R16.1, R19.2, R21.2, R22.2, R23.2, R26.2, R31.1, R32.1, R33.1, R37.2, R38.2, R39.2, SD1.PIN4 (3.3V), U1.8 (VDD), U1.18 (VDD), U1.30 (VDD), U1.40 (VDD), U2.8 (VCC), U5.2 (OUT), U5.PAD (OUT), U6.8 (VCC), U9.1 (VCC), U20.2 (SOURCE), U21.5 (VCC)
3.3V_ANALOG: C18.1, C19.1, C24.1, C26.1, C27.1, C46.1, C47.1, C51.1, C52.1, C58.1, C59.1, C63.1, C64.1, C68.1, C69.1, C73.1, C74.1, R35.1, U11.P$5 (AVDD), U11.P$8 (DVDD), U12.P$5 (AVDD), U12.P$8 (DVDD), U13.P$5 (AVDD), U13.P$8 (DVDD), U14.P$5 (AVDD), U14.P$8 (DVDD), U15.P$5 (AVDD), U15.P$8 (DVDD), U16.P$5 (AVDD), U16.P$8 (DVDD), U17.P$5 (AVDD), U17.P$8 (DVDD), U18.P$5 (AVDD), U18.P$8 (DVDD)
3V3OUT: C11.1, U4.1 (VCCIO), U4.8 (3V3OUT)
!PWREN: R19.1, U4.14 (CBUS3), U21.3 (2A)
!SLEEP: U4.11 (CBUS1), U21.1 (1A)
A: J6.P$1 (PIN1), R36.2
ADC_0_!CS: U1.13 (P12), U11.P$9 (!CS)
ADC_1_!CS: U1.14 (P13), U12.P$9 (!CS)
ADC_2_!CS: U1.15 (P14), U13.P$9 (!CS)
ADC_3_!CS: U1.16 (P15), U14.P$9 (!CS)
ADC_4_!CS: U1.19 (P16), U15.P$9 (!CS)
ADC_5_!CS: U1.20 (P17), U16.P$9 (!CS)
ADC_6_!CS: U1.21 (P18), U17.P$9 (!CS)
ADC_7_!CS: U1.22 (P19), U18.P$9 (!CS)
ADC_SCK: U1.12 (P11), U11.P$10 (SCK), U12.P$10 (SCK), U13.P$10 (SCK), U14.P$10 (SCK), U15.P$10 (SCK), U16.P$10 (SCK), U17.P$10 (SCK), U18.P$10 (SCK)
ADC_SDI: U1.10 (P9), U11.P$12 (SDI), U12.P$12 (SDI), U13.P$12 (SDI), U14.P$12 (SDI), U15.P$12 (SDI), U16.P$12 (SDI), U17.P$12 (SDI), U18.P$12 (SDI)
ADC_SDO: U1.11 (P10), U11.P$11 (SDO), U12.P$11 (SDO), U13.P$11 (SDO), U14.P$11 (SDO), U15.P$11 (SDO), U16.P$11 (SDO), U17.P$11 (SDO), U18.P$11 (SDO)
A_0: C39.1, R29.2, R30.1, U9.3 (A_0)
BCD_CHARGER: R20.2, U4.5 (CBUS2), U10.5 (EN2)
CHARGING: R15.2, U1.23 (P20), U10.9 (!CHG)
D+: C82.1, R11.1, U19.3 (I/O1B)
D-: C81.1, R10.1, U19.4 (I/O2B)
EXT0: OP1.1, U1.34 (P27)
EXT1: OP1.3, U1.33 (P26)
EXT_CON_0: J1.1, OP1.8
EXT_CON_1: J1.2, OP1.7
EXT_CON_2: J1.3, OP1.6
EXT_CON_3: J1.4, OP1.5
FT230_RST: C40.1, R31.2, U1.24 (P21), U4.9 (RESET#)
GND: BATT1.N (-), C1.2, C2.2, C3.2, C4.2, C5.2, C6.2, C7.2, C8.2, C9.2, C10.2, C11.2, C13.2, C14.2, C15.2, C17.2, C18.2, C19.2, C21.2, C22.2, C23.2, C24.2, C25.2, C26.2, C27.2, C29.2, C30.2, C31.2, C32.2, C33.2, C37.2, C38.2, C39.2, C40.2, C42.2, C43.2, C44.2, C45.N (NEG), C46.2, C47.2, C49.2, C50.2, C51.2, C52.2, C53.N (NEG), C56.2, C57.2, C58.2, C59.2, C61.2, C62.2, C63.2, C64.2, C66.2, C67.2, C68.2, C69.2, C71.2, C72.2, C73.2, C74.2, C81.2, C82.2, C83.2, D1.CATHODE, D4.3, D5.3, D6.3, D7.3, D8.3, D9.3, D10.3, D11.3, D12.CATHODE, J3.5 (GND), J4.P$1 (PIN1), J4.P$2 (PIN2), J6.P$2 (PIN2), L2.2, R14.2, R17.2, R18.2, R20.1, R28.1, R30.2, R34.1, SD1.G0 (GND), SD1.G1 (GND), SD1.PIN6 (GND), SW2.1 (A), SW2.2 (A), SW3.1 (A), SW3.2 (A), SW4.1 (A), SW4.2 (A), SW5.1 (A), SW5.2 (A), U1.5 (VSS), U1.6 (BOE'), U1.17 (VSS), U1.27 (VSS), U1.39 (VSS), U2.1 (A0), U2.2 (A1), U2.3 (A2), U2.4 (GND), U2.7 (WP), U4.3 (GND), U4.13 (GND), U4.PAD (GND), U5.1 (GND), U6.4 (VSS), U7.2 (SOURCE), U9.2 (GND), U10.8 (VSS), U10.15 (SYSOFF), U10.PAD0 (VSS), U10.PAD1 (VSS), U11.P$1 (AGND), U11.P$14 (DGND), U12.P$1 (AGND), U12.P$14 (DGND), U13.P$1 (AGND), U13.P$14 (DGND), U14.P$1 (AGND), U14.P$14 (DGND), U15.P$1 (AGND), U15.P$14 (DGND), U16.P$1 (AGND), U16.P$14 (DGND), U17.P$1 (AGND), U17.P$14 (DGND), U18.P$1 (AGND), U18.P$14 (DGND), U19.2 (GND), U21.2 (GND), X1.P$2 (GND), X1.P$4 (GND)
ILM: R17.1, U10.12 (ILM)
IRQ: R2.1, SD1.PIN8 (IRQ)
ISET: R18.1, U10.16 (ISET)
LCD_BKLT: R37.1, U1.4 (P7), U20.1 (GATE)
LCD_RST: J4.P$5 (PIN5), U1.3 (P6)
LCD_SCL: J4.P$16 (PIN16), R39.1, U1.1 (P4)
LCD_SDA: J4.P$11 (PIN11), J4.P$12 (PIN12), J4.P$13 (PIN13), J4.P$15 (PIN15), R38.1, U1.2 (P5)
unnamed: C54.1, C75.1, J4.P$17 (PIN17), J4.P$18 (PIN18), J4.P$19 (PIN19), J4.P$20 (PIN20)
unnamed: D1.ANODE, R13.2
unnamed: C35.1, D3.CATHODE, R25.1, SW5.3 (B), SW5.4 (B)
unnamed: C36.2, R27.2, U7.1 (GATE)
unnamed: OP1.2, R28.2
unnamed: R36.1, U20.3 (DRAIN)
unnamed: C54.2, C75.2, J4.P$21 (PIN21), J4.P$22 (PIN22), J4.P$23 (PIN23), J4.P$24 (PIN24)
unnamed: C80.1, J4.P$25 (PIN25)
unnamed: C79.1, J4.P$27 (PIN27)
unnamed: C78.1, J4.P$28 (PIN28)
unnamed: C77.1, J4.P$29 (PIN29)
unnamed: C76.1, J4.P$30 (PIN30)
unnamed: C76.2, C77.2, C78.2, C79.2, C80.2
unnamed: D12.ANODE, R32.2
unnamed: J3.2 (D-), U19.6 (I/O2A)
unnamed: OP1.4, R34.2
unnamed: C23.1, L18.P$1, R35.2
unnamed: J3.3 (D+), U19.1 (I/O1A)
unnamed: J3.S1 (SLD), J3.S2 (SLD), J3.S3 (SLD), J3.S4 (SLD), J3.S5 (SLD), J3.S6 (SLD), L2.1
PGOOD: R16.2, U10.7 (!PGOOD)
PWREN: U10.6 (EN1), U21.4 (2Y)
PWR_SW: D3.ANODE, R26.1, R27.1, U1.32 (P25)
RES: R1.1, SW1.3 (B), SW1.4 (B), U1.7 (RES')
RTC_X1: U6.1 (X1), X2.1
RTC_X2: U6.2 (X2), X2.4
RTS: C12.1, U4.16 (RTS#)
RX: U1.37 (P30), U4.2 (RXD)
SCL: R8.1, U1.35 (P28), U2.6 (SCL), U6.6 (SCL), U9.5 (SCL)
SDA: R9.1, U1.36 (P29), U2.5 (SDA), U6.5 (SDA), U9.4 (SDA)
SD_CS: R6.1, SD1.PIN2 (CS), U1.44 (P3)
SD_DI: R5.1, SD1.PIN3 (DI), U1.43 (P2)
SD_DO: R3.1, SD1.PIN7 (D0), U1.41 (P0)
SD_RW: R7.1, SD1.PIN1 (RW)
SD_SCLK: R4.1, SD1.PIN5 (SCLK), U1.42 (P1)
SLEEP: U10.4 (!CE), U21.6 (1Y)
SW_DWN: R23.1, SW4.3 (B), SW4.4 (B), U1.31 (P24)
SW_SEL: R22.1, SW3.3 (B), SW3.4 (B), U1.26 (P23)
SW_UP: R21.1, SW2.3 (B), SW2.4 (B), U1.25 (P22)
SYS_V: C32.1, C34.1, R24.2, R25.2, U6.3 (V_BACK), U8.2 (SOURCE), U10.10 (OUT), U10.11 (OUT)
SYS_V_SW: C7.1, C9.1, U5.3 (IN), U8.3 (DRAIN)
S_P_G: C34.2, C35.2, R24.1, U7.3 (DRAIN), U8.1 (GATE)
TP_T+_0: C16.2, C17.1, D4.1, T1.POS, U11.P$4 (T+)
TP_T+_1: C20.2, C22.1, D5.1, T2.POS, U12.P$4 (T+)
TP_T+_2: C28.2, C30.1, D6.1, T3.POS, U13.P$4 (T+)
TP_T+_3: C48.2, C50.1, D7.1, T4.POS, U14.P$4 (T+)
TP_T+_4: C55.2, C57.1, D8.1, T5.POS, U15.P$4 (T+)
TP_T+_5: C60.2, C62.1, D9.1, T6.POS, U16.P$4 (T+)
TP_T+_6: C65.2, C67.1, D10.1, T7.POS, U17.P$4 (T+)
TP_T+_7: C70.2, C72.1, D11.1, T8.POS, U18.P$4 (T+)
TP_T-_0: C15.1, C16.1, D4.2, T1.NEG, U11.P$2 (BIAS), U11.P$3 (T-)
TP_T-_1: C20.1, C21.1, D5.2, T2.NEG, U12.P$2 (BIAS), U12.P$3 (T-)
TP_T-_2: C28.1, C29.1, D6.2, T3.NEG, U13.P$2 (BIAS), U13.P$3 (T-)
TP_T-_3: C48.1, C49.1, D7.2, T4.NEG, U14.P$2 (BIAS), U14.P$3 (T-)
TP_T-_4: C55.1, C56.1, D8.2, T5.NEG, U15.P$2 (BIAS), U15.P$3 (T-)
TP_T-_5: C60.1, C61.1, D9.2, T6.NEG, U16.P$2 (BIAS), U16.P$3 (T-)
TP_T-_6: C65.1, C66.1, D10.2, T7.NEG, U17.P$2 (BIAS), U17.P$3 (T-)
TP_T-_7: C70.1, C71.1, D11.2, T8.NEG, U18.P$2 (BIAS), U18.P$3 (T-)
TS: R14.1, U10.1 (TS)
TX: U1.38 (P31), U4.15 (TXD)
TXRX_LED: U4.12 (CBUS0)
USBDM: R10.2, U4.7 (USBDM)
USBDP: R11.2, U4.6 (USBDP)
USB_RST: C12.2, R33.2, SW1.1 (A), SW1.2 (A), U1.9 (P8)
USB_V0: J3.1 (5V), L1.1, U19.5 (VB)
USB_V1: C13.1, C14.1, C33.1, L1.2, R13.1, U4.10 (VCC), U10.13 (IN)
VBATT: BATT1.P (+), C31.1, R29.1, U10.2 (BAT), U10.3 (BAT)
X0: U1.29 (X0), X1.P$3 (X1)
X1: U1.28 (X1), X1.P$1 (X0)

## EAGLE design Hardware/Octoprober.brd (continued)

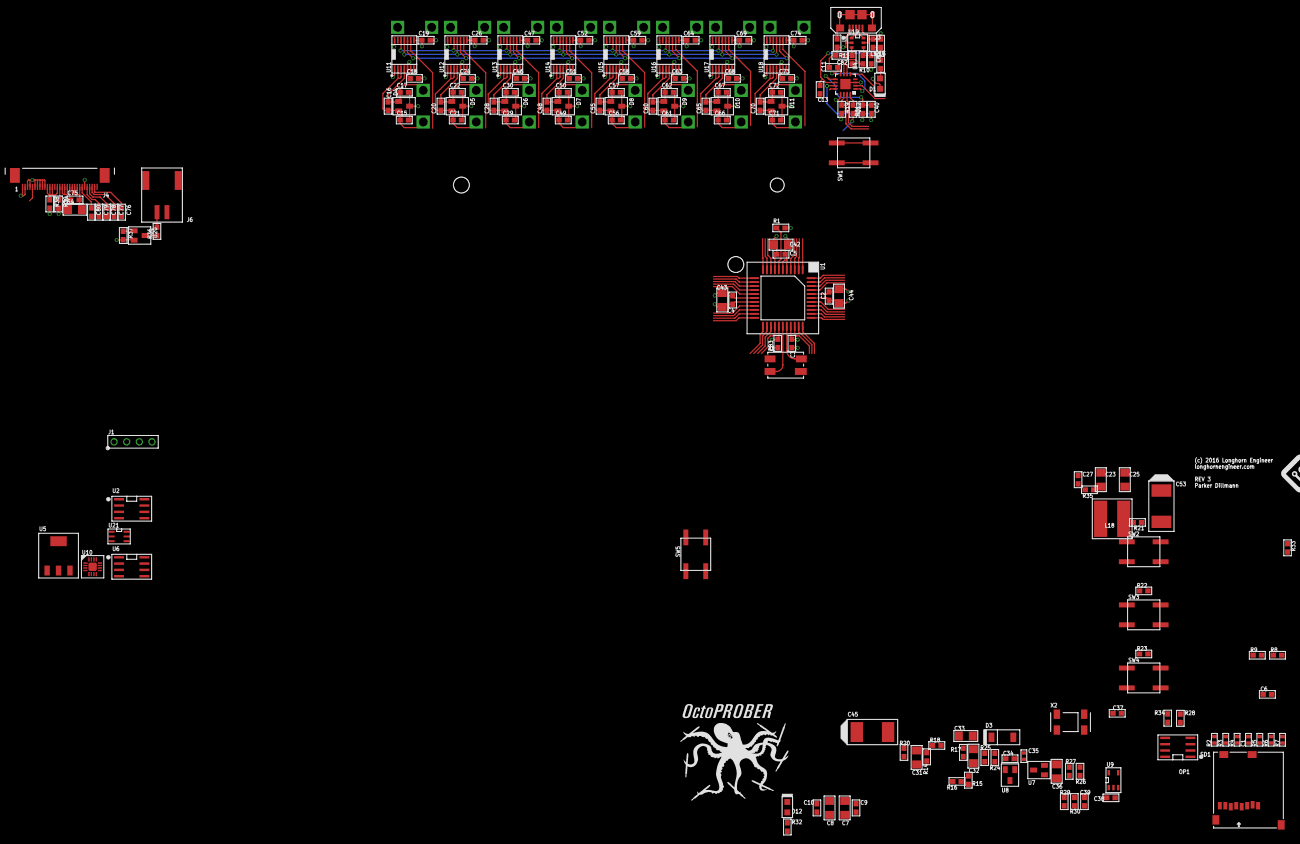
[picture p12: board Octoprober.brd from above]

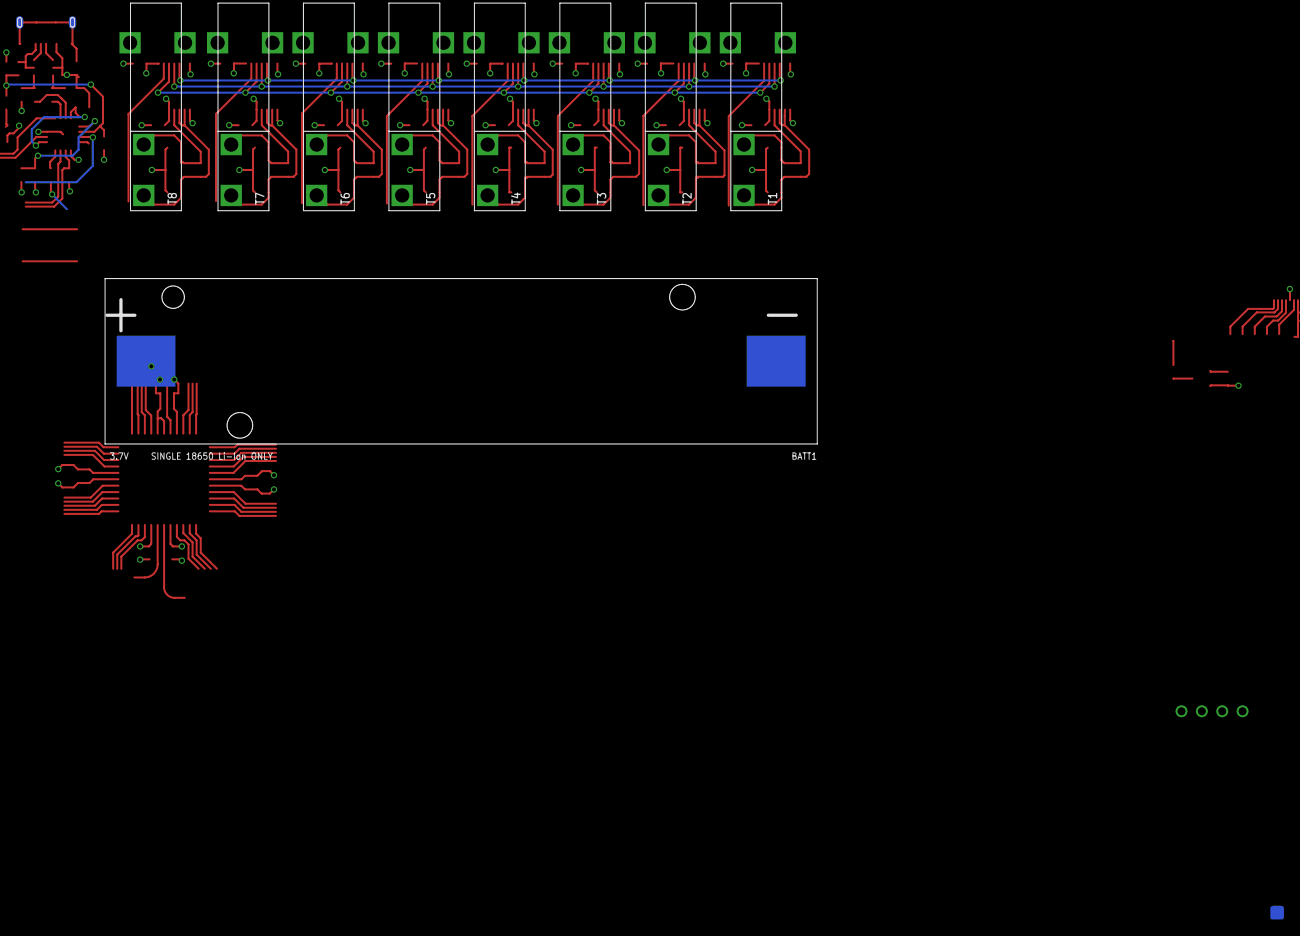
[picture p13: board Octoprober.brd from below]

Board: 4 copper layers, 179 parts (9 on the bottom side), 104 nets.

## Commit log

2013-12-16 Commit first schematic. Need to figure out power.
    [Octoprober.sch]
2013-12-16 Added lithium battery. Still need to add charger.
    [Octoprober.sch]
2013-12-17 Added BQ24075RGTT for charging.
    [Octoprober.sch]
2013-12-18 Still need Battery Monitoring Solution
    [Octoprober.sch]
2013-12-19 Added Soft power switch
    Soft power circuit to enable MCU to initiate a shutdown of the system to
    prevent corruption of the SD Card.
    [Octoprober.sch]
2013-12-19 Added ADC. Might use it for battery voltage level.
    [Octoprober.sch]
2013-12-31 Created Board. Still need to figure out connector
    [Octoprober.brd, Octoprober.sch]
2014-01-06 Worked on the layout some more.
    Still need lots of work and connectors.
    [Octoprober.brd, Octoprober.sch]
2014-01-07 Add optocouple.
    [Octoprober.brd, Octoprober.sch]
2014-01-07 Finished preliminary routing
    [Octoprober.brd, Octoprober.sch]
2014-01-07 Added Schematic image.
2014-01-10 Added RTC.
    [Octoprober.brd, Octoprober.sch]
2014-01-10 New Schematic image
2014-01-10 Rerouted I/O for LCD around mounting hole
    [Octoprober.brd]
2014-01-11 Working on Silkscreen
    [Octoprober.brd]
2014-01-12 Fixed some traces. Looking good. Silkscreen next.
    [Octoprober.brd]
2014-01-13 Added TVS to TC lines.
    [Octoprober.brd, Octoprober.sch]
2014-01-13 Finished REV0.
    [Octoprober.brd, Octoprober.sch]
2014-01-14 Added ADC MCP3021 to monitor battery
    [Octoprober.brd, Octoprober.sch]
2014-01-27 Push Schematic image
2014-01-28 Added part values and created BOM.txt
    [Octoprober.brd, Octoprober.sch]
2014-01-28 Fixed some part numbers
    [Octoprober.brd, Octoprober.sch]
2014-01-28 Finished BOM...I hope.
    [Octoprober.brd, Octoprober.sch]
2014-01-31 Swapped VCC and VDD on display
    [Octoprober.brd, Octoprober.sch]
2014-01-31 Updated display footprint
    [Octoprober.brd, Octoprober.sch]
2014-01-31 Evened out power traces on C17
    [Octoprober.brd]
2014-02-04 Changed footprint for Regulator
    [Octoprober.brd, Octoprober.sch]
2014-02-04 Changed FT230X RST to be controlled by PROP
    [Octoprober.brd, Octoprober.sch]
2014-02-04 Added cap to FT230X RST line.
    [Octoprober.brd, Octoprober.sch]
2014-02-04 Fixed screw terminal footprints.
    [Octoprober.brd, Octoprober.sch]
2014-02-05 Cleaned up LCD Driver
2014-02-06 LCD Screen is Serial now.
    Wrote spin code for Serial interface.
    [Octoprober.brd, Octoprober.sch]
2014-02-06 Added code for Reset function.
    [Octoprober.brd, Octoprober.sch]
2014-02-08 Added code to get ADC MCP3021 working
2014-02-10 Added driver for the MAX31855. Needs rewrite.
2014-02-11 REV1 finished routing. Need to increase font size.
    [Octoprober.brd, Octoprober.sch]
2014-02-11 Changed line weights. Need to test SD card slot.
    [Octoprober.brd, Octoprober.sch]
2014-02-12 Fixed SD card. Need GND pin routed.
    [Octoprober.brd]
2014-02-12 Updating Layout and Schematic images.
2014-02-24 Updated LCD display to be wider. Fixed a Via dia.
    [Octoprober.brd, Octoprober.sch]
2014-02-25 Updated BOM to current
2014-02-25 Updated Crystal part number
    [Octoprober.brd, Octoprober.sch]
2014-02-25 Fixed layout of display
    [Octoprober.brd, Octoprober.sch]
2014-03-05 Added more decoupling around the Propeller
    [Octoprober.brd, Octoprober.sch]
2014-03-06 Removed MAX31855. Added MCP3424 instead!
    [Octoprober.brd, Octoprober.sch]
2014-03-07 Finished the new MCP3424 and AT30TSE752-XM8-T
    [Octoprober.brd, Octoprober.sch]
2014-03-14 Added another 470uF cap
    [Octoprober.brd, Octoprober.sch]
2014-03-17 Added 560ohm resistor to discharge caps.
    [Octoprober.brd, Octoprober.sch]
2014-03-18 Fixed FT230X to support BC1.2 chargers.
2014-03-19 REV 2 push
    [Octoprober.brd, Octoprober.sch]
2014-03-19 Latest BOM.txt
2015-01-12 Merged with Octocoder.
    [Octoprober.brd, Octoprober.sch]
2015-10-22 New chips for thermocouples.
    [Octoprober.brd, Octoprober.sch]
2015-10-23 Working on LCD setup. Need to find a case.
    [Octoprober.brd, Octoprober.sch]
2015-10-23 Thermocouple connectors added.
    [Octoprober.brd, Octoprober.sch]
2015-11-02 Switched display to a ERC128128FS
    [Octoprober.brd, Octoprober.sch]
2016-06-24 starting on the revamp.
    [Octoprober.brd, Octoprober.sch]
2016-06-27 Working on new rev. Need to route.
    [Octoprober.brd, Octoprober.sch]
2016-06-28 Started routing REV3.
    [Octoprober.brd, Octoprober.sch]
2016-07-12 More work to check in.
    [Octoprober.brd, Octoprober.sch]

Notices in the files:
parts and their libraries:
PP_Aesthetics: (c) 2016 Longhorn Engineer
